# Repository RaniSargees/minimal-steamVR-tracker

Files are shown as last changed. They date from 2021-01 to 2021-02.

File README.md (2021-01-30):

# minimal-steamVR-tracker
a bare-minimum hand-solderable steamVR tracker, based on http://hivetracker.github.io/

The firmware for this does not yet exist.

Arduino is incompatible with the nrf52810, so this design does not work with the hivetracker firmware. This can be changed by replacing the [Laird bl651](https://www.lairdconnect.com/wireless-modules/bluetooth-modules/bluetooth-5-modules/bl651-series-bluetooth-module) module with the compatible nrf52832-based [Laird bl652](https://www.lairdconnect.com/wireless-modules/bluetooth-modules/bluetooth-5-modules/bl652-series-bluetooth-v5-nfc-module). The design does not need to be changed.

Additionally, the IMU has been changed from the BNO055 to the *much* cheaper MPU-6050. If using the hivetracker firmware, it will need to be modified to support this different IMU.

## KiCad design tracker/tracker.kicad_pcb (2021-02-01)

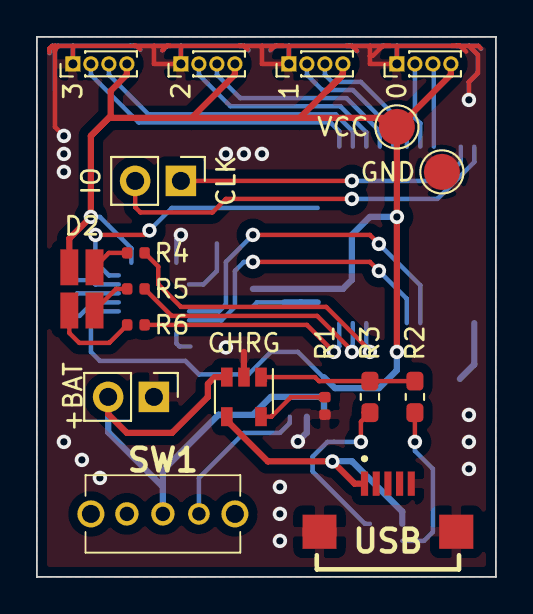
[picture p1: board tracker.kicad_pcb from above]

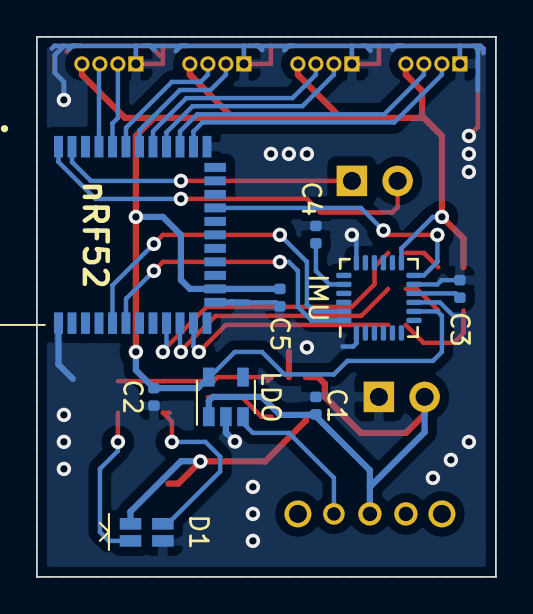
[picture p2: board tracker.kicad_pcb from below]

Board: 2 copper layers, 25.5 x 30.0 mm, 27 parts (9 on the bottom side), 30 nets.

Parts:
0: Chiclet0; PinHeader_1x04_P1.00mm_Vertical
1: Chiclet1; PinHeader_1x04_P1.00mm_Vertical
2: Chiclet2; PinHeader_1x04_P1.00mm_Vertical
3: Chiclet3; PinHeader_1x04_P1.00mm_Vertical
+BAT: Battery; PinHeader_1x02_P2.54mm_Vertical
C1, C2, C5: 1uf; C_0402_1005Metric
C3: 0.1uf; C_0402_1005Metric
C4: 2.2nf; C_0402_1005Metric
CHRG: MCP73831-2-OT; SOT-23-5
D1: LED_Dual_AACC; 1616LED
D2: LED_BGRA; 0404LED
GND: TestPoint; TestPoint_Pad_D2.0mm
IMU: MPU-6050; InvenSense_QFN-24_4x4mm_P0.5mm
J7: SWD; PinHeader_1x02_P2.54mm_Vertical
LDO: MIC5504-3.3YM5; SOT-23-5
R1: 2K; R_0402_1005Metric
R2, R3: 330; C_0603_1608Metric_Pad1.05x0.95mm_HandSolder
R4: 300; R_0402_1005Metric
R5, R6: 82; R_0402_1005Metric
SW1: Power Switch; 18252321
USB: USB_B_Micro; 101181920001LF
VCC: TestPoint; TestPoint_Pad_D2.0mm
nRF52: 453-00005; 45300005

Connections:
+BATT: +BAT.2, C1.2, CHRG.3, LDO.1, SW1.2
B: R6.2, nRF52.29
D0: 0.2, nRF52.9
D1: 1.2, nRF52.11
D2: 2.2, nRF52.13
D3: 3.2, nRF52.15
E0: 0.3, nRF52.8
E1: 1.3, nRF52.10
E2: 2.3, nRF52.12
E3: 3.3, nRF52.14
G: R5.2, nRF52.30
GND: 0.1, 1.1, 2.1, 3.1, +BAT.1, C1.1, C2.1, C3.2, C4.2, C5.1, CHRG.2, D1.4, GND.1, IMU.1, IMU.9, IMU.11, IMU.18, LDO.2, R1.1, USB.5, USB.6, nRF52.16, nRF52.27, nRF52.39
INT1: IMU.12, nRF52.20
unnamed: C3.1, IMU.10
unnamed: C4.1, IMU.20
unnamed: D1.2, R2.2
unnamed: D1.3, R3.1
unnamed: D2.1, R6.1
unnamed: D2.2, R5.1
unnamed: D2.3, R4.1
unnamed: J7.2, nRF52.5
unnamed: J7.1, nRF52.6
unnamed: CHRG.5, R1.2
unnamed: CHRG.1, R2.1, R3.2
unnamed: LDO.3, SW1.3
R: R4.2, nRF52.31
SCL: IMU.23, nRF52.35
SDA: IMU.24, nRF52.34
VBUS: CHRG.4, D1.1, USB.1
VCC: 0.4, 1.4, 2.4, 3.4, C2.2, C5.2, D2.4, IMU.8, IMU.13, LDO.5, VCC.1, nRF52.26

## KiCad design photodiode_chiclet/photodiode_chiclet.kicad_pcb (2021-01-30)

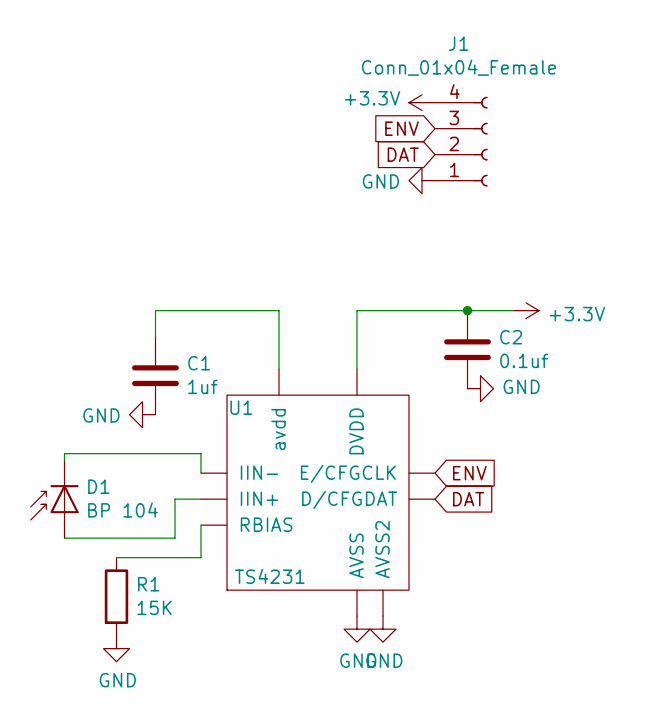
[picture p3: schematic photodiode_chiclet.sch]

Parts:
C1: 1uf; C_0402_1005Metric
C2: 0.1uf; C_0402_1005Metric
D1: BP 104; DIO_BP_104_S-Z
J1: Conn_01x04_Female; PinHeader_1x04_P1.00mm_Horizontal
R1: 15K; R_0402_1005Metric
U1: TS4231

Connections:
+3V3: C2.1, J1.4, U1.C3 (DVDD)
DAT: J1.2, U1.C1 (D/CFGDAT)
ENV: J1.3, U1.C2 (E/CFGCLK)
GND: C1.2, C2.2, J1.1, R1.2, U1.B2 (AVSS)
unnamed: C1.1, U1.A1 (avdd)
unnamed: D1.1 (K), U1.A3 (IIN-)
unnamed: D1.2 (A), U1.A2 (IIN+)
unnamed: R1.1, U1.B1 (RBIAS)

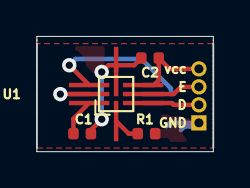
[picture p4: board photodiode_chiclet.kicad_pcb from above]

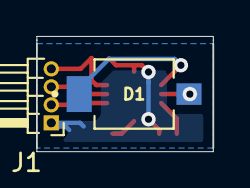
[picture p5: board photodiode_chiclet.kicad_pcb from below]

Board: 2 copper layers, 9.8 x 6.4 mm, 6 parts (2 on the bottom side), 8 nets.

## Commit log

2021-01-30 add chiclet photodiode board design
    [photodiode_chiclet.kicad_pcb, photodiode_chiclet.sch]
2021-02-01 add main tracking board designs
    [tracker.kicad_pcb, tracker.sch]
